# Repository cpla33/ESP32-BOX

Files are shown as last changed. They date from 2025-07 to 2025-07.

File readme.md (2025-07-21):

# ESP32-BOX

The device has been designed around regular ESP32-module to be fitted inside DIN-rail mounting enclosure. The board designed to be compact as much as possible. It takes 3 DIN-rail positions only.

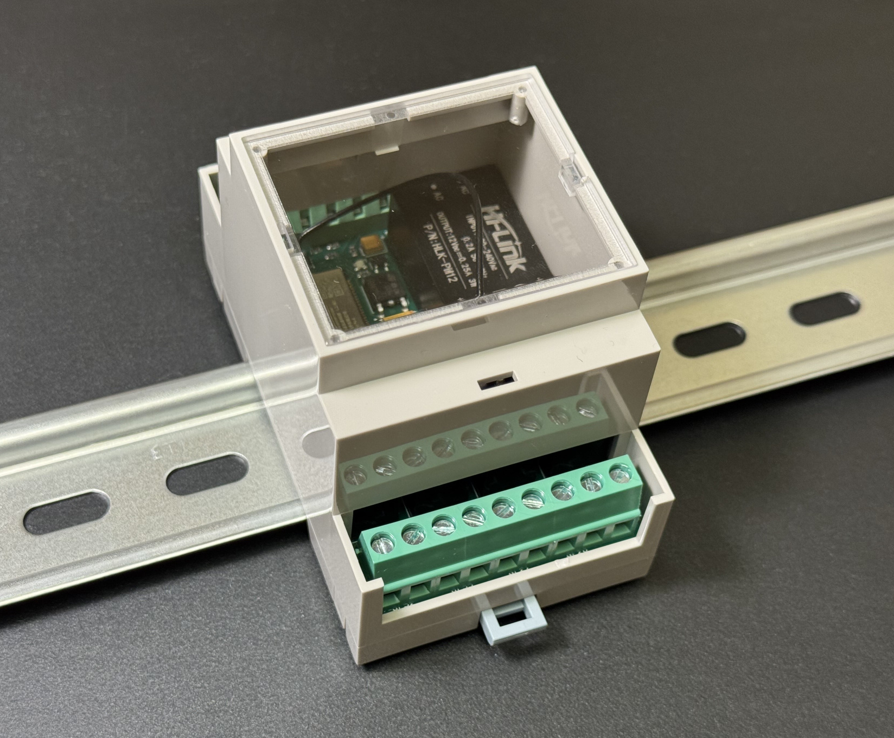
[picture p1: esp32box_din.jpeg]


------

### Main features:

- The **ESP32-BOX** has internal AC/DC-converter. Thus it could be powered from the regular AC line (i.e. wall socket) 100-240V (no external AC/DC adapters needed);
- The **ESP32-BOX** provides 4 optically isolated Relay outputs (up to 10A/250V or 5A/30V each). Each relay output has its own LED-indicator.
- The **ESP32-BOX** provides 4 GPIOs. Two of them could be used as I2C-line.
- All the inputs and outputs of the **ESP32-BOX** are implemented as reliable screw terminals.
- The **ESP32-BOX** has onboard RGB-led, which could be used for multiple status indications on your taste.
- The top part of the enclosure is transparent. So the LEDs could be easily observed from the outside.
- The **ESP32-BOX** provides powerful external antenna, which is located inside the enclosure. Thanks to `uFL/IPEX1` header any other suitable antenna could be used instead.
- The **ESP32-BOX** is equipped with the external +3dBi antenna hidden inside the enclosure;
- The **ESP32-BOX** could be programmed with the USB Type-C cable (no buttons required).
- The **ESP32-BOX** could be programmed with the ; write your sketches whenever you want: Arduino, CircuitPython, MicroPython or ESP-IDF.
- Finally, **ESP32-BOX** is **ESPHome**-compatible!

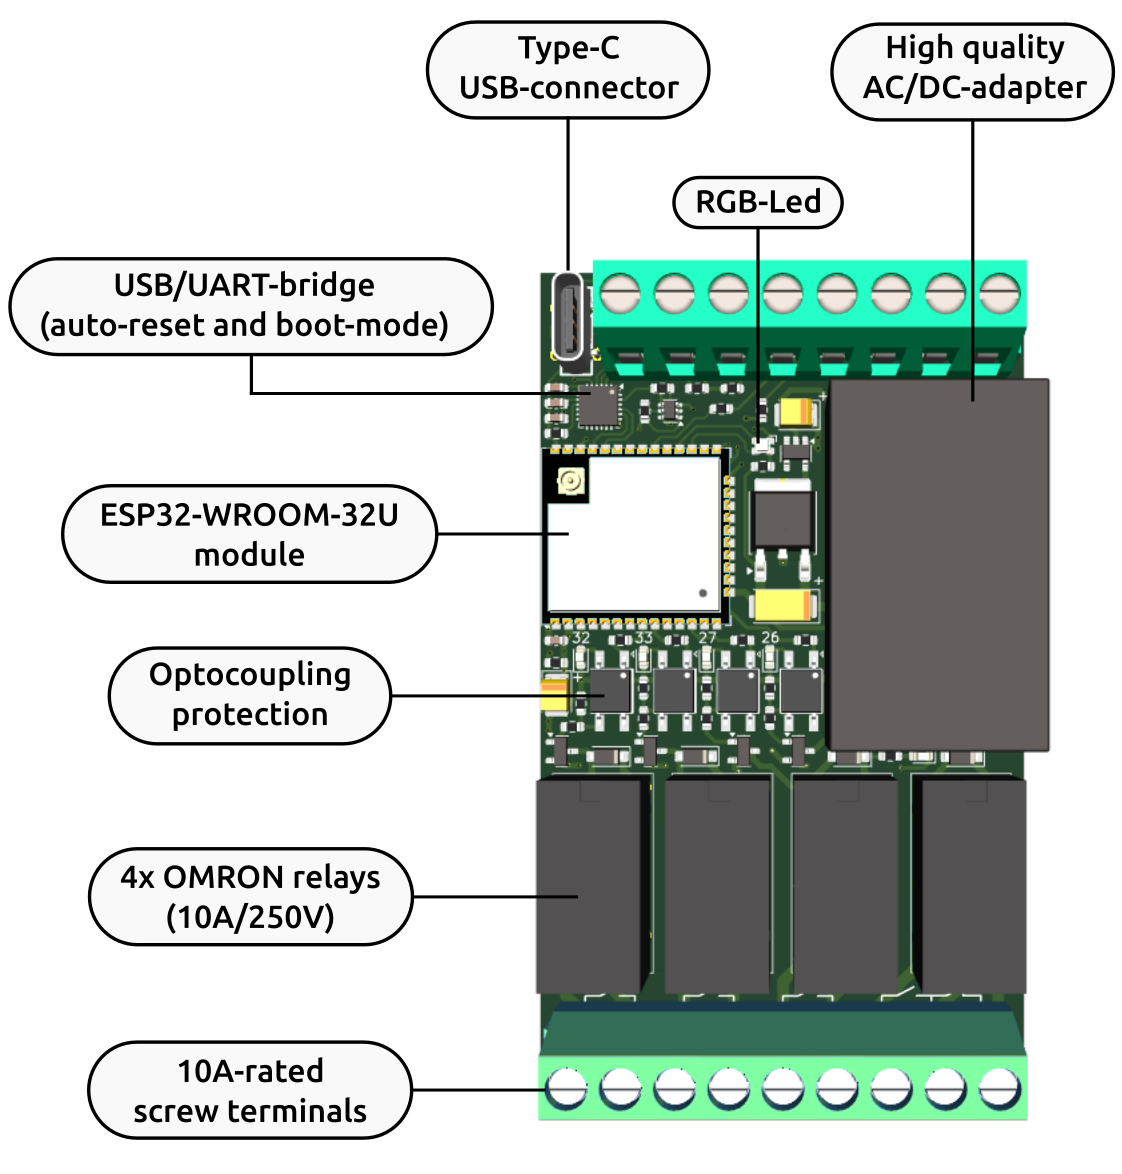
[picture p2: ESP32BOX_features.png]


------

### Programming:

A number of different IDEs and programming languages of any taste as below are allowed to program the **ESP32-BOX**:

[ESPHome](https://www.binarytechlabs.com/how-to-flash-esphome-firmware-a-friendly-step-by-step-guide/)

[Arduino](https://randomnerdtutorials.com/installing-the-esp32-board-in-arduino-ide-windows-instructions/)

[CircuitPython](FIRMWARE/CIRCUITPYTHON/readme_circuitpython.md)

[MicroPython](https://micropython.org/download/ESP32_GENERIC/)

[ESP-IDF](https://docs.espressif.com/projects/esp-idf/en/stable/esp32/get-started/index.html)

A couple of different examples could be found in the [FIRMWARE](FIRMWARE/) folder.

------

### Pinout:

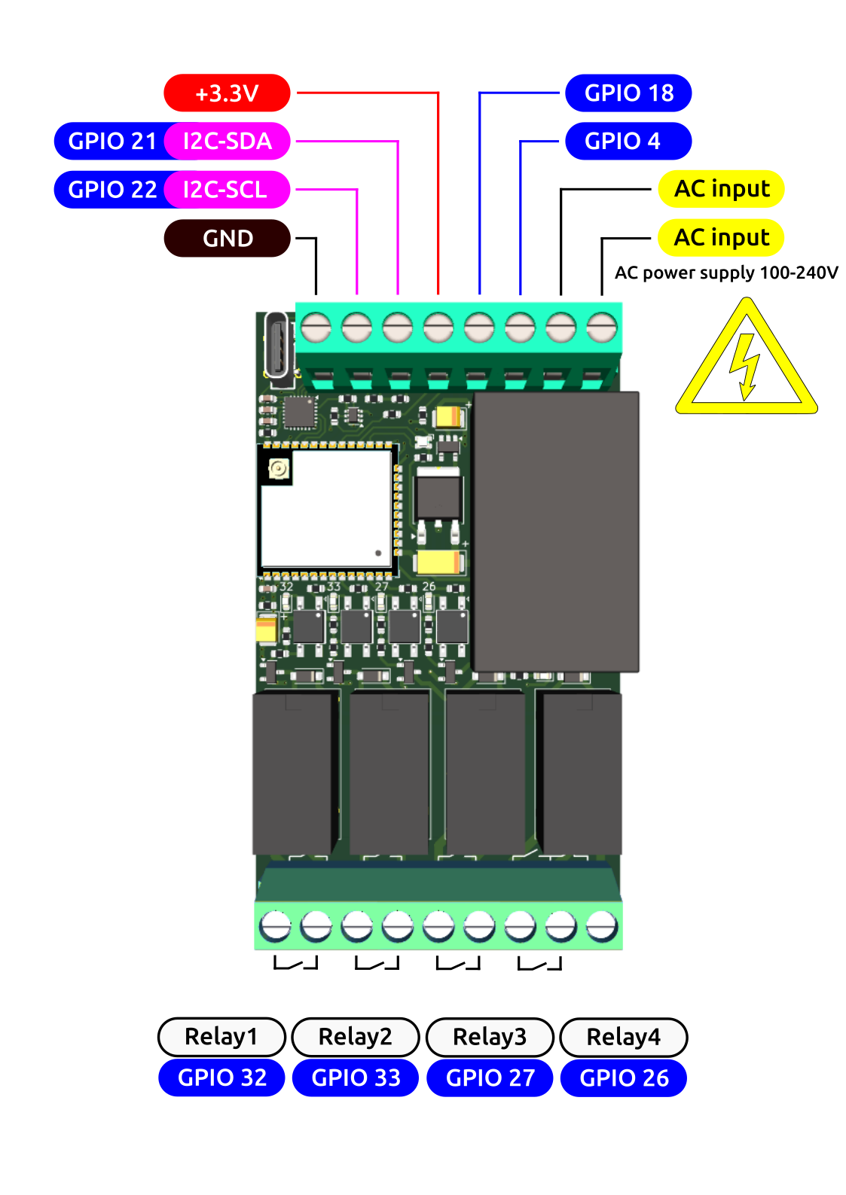
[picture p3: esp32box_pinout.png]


------

### Schematics:

Refer to the [schematics](HARDWARE/esp32_box_single.pdf) if needed.

------

Coming soon at Lectronz.com

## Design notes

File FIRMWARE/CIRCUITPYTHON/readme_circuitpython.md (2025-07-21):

### Uploading the CircuitPython firmware in Linux:

1. Download [latest firmware](https://circuitpython.org/board/espressif_esp32_devkitc_v4_wroom_32e/) file from official CircuitPython web-site.

2. Install [esptool](https://github.com/espressif/esptool) as below:

```bash
python3 -m pip install --upgrade esptool
```

3. Plug-in USB-C cable and check for device connection:

```bash
ls /dev/ttyACM0
```

4. Erase flash as below:

```bash
esptool.py --chip esp32 --port /dev/ttyACM0 erase_flash
```

5. Write the CircuitPython firmware:

```bash
esptool.py --chip esp32 --port /dev/ttyACM0 \
           --baud 460800 \
           --after hard_reset \
           write_flash -z 0x0 adafruit-circuitpython-espressif_esp32_devkitc_v4_wroom_32e-en_US-9.2.8.bin
           
```

More options could be found [here](https://learn.adafruit.com/circuitpython-with-esp32-quick-start/command-line-esptool).

------

### Code examples:

Code examples could be found in [EXAMPLES](EXAMPLES/test_io.py) directory.

------
[Back](../../readme.md)

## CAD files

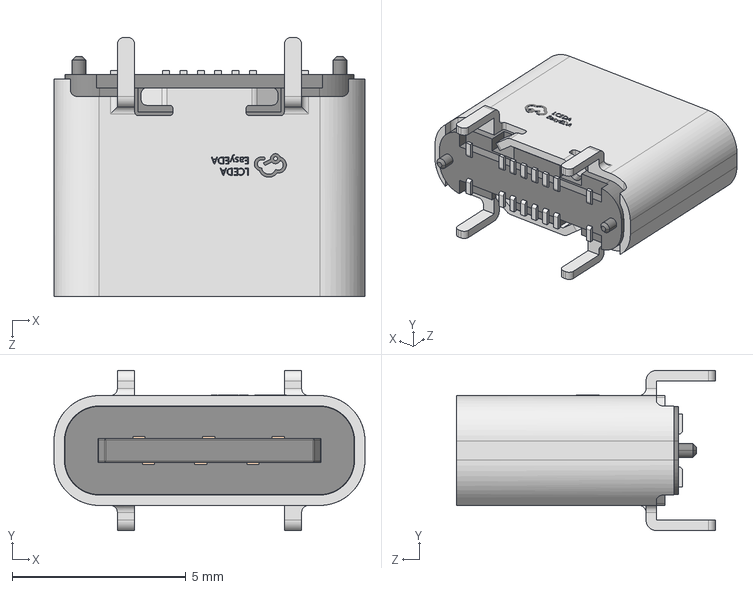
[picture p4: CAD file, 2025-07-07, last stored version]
HARDWARE/kicad/esp32_box_single/models/C3151749_TYPE-C-SMD_USB4120-03-C.step
8.94 x 4.60 x 7.45 mm

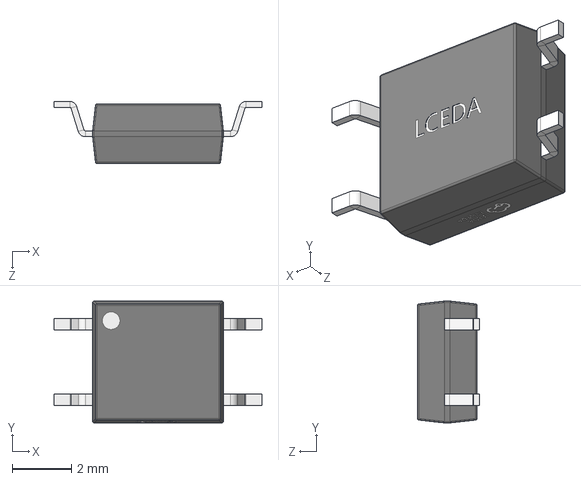
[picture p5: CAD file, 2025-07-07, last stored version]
HARDWARE/kicad/esp32_box_single/models/C42381015_EL357_OPTO-SMD-4_L4.4-W4.1-P2.54-LS7.0-TL.step
7.00 x 4.10 x 2.08 mm

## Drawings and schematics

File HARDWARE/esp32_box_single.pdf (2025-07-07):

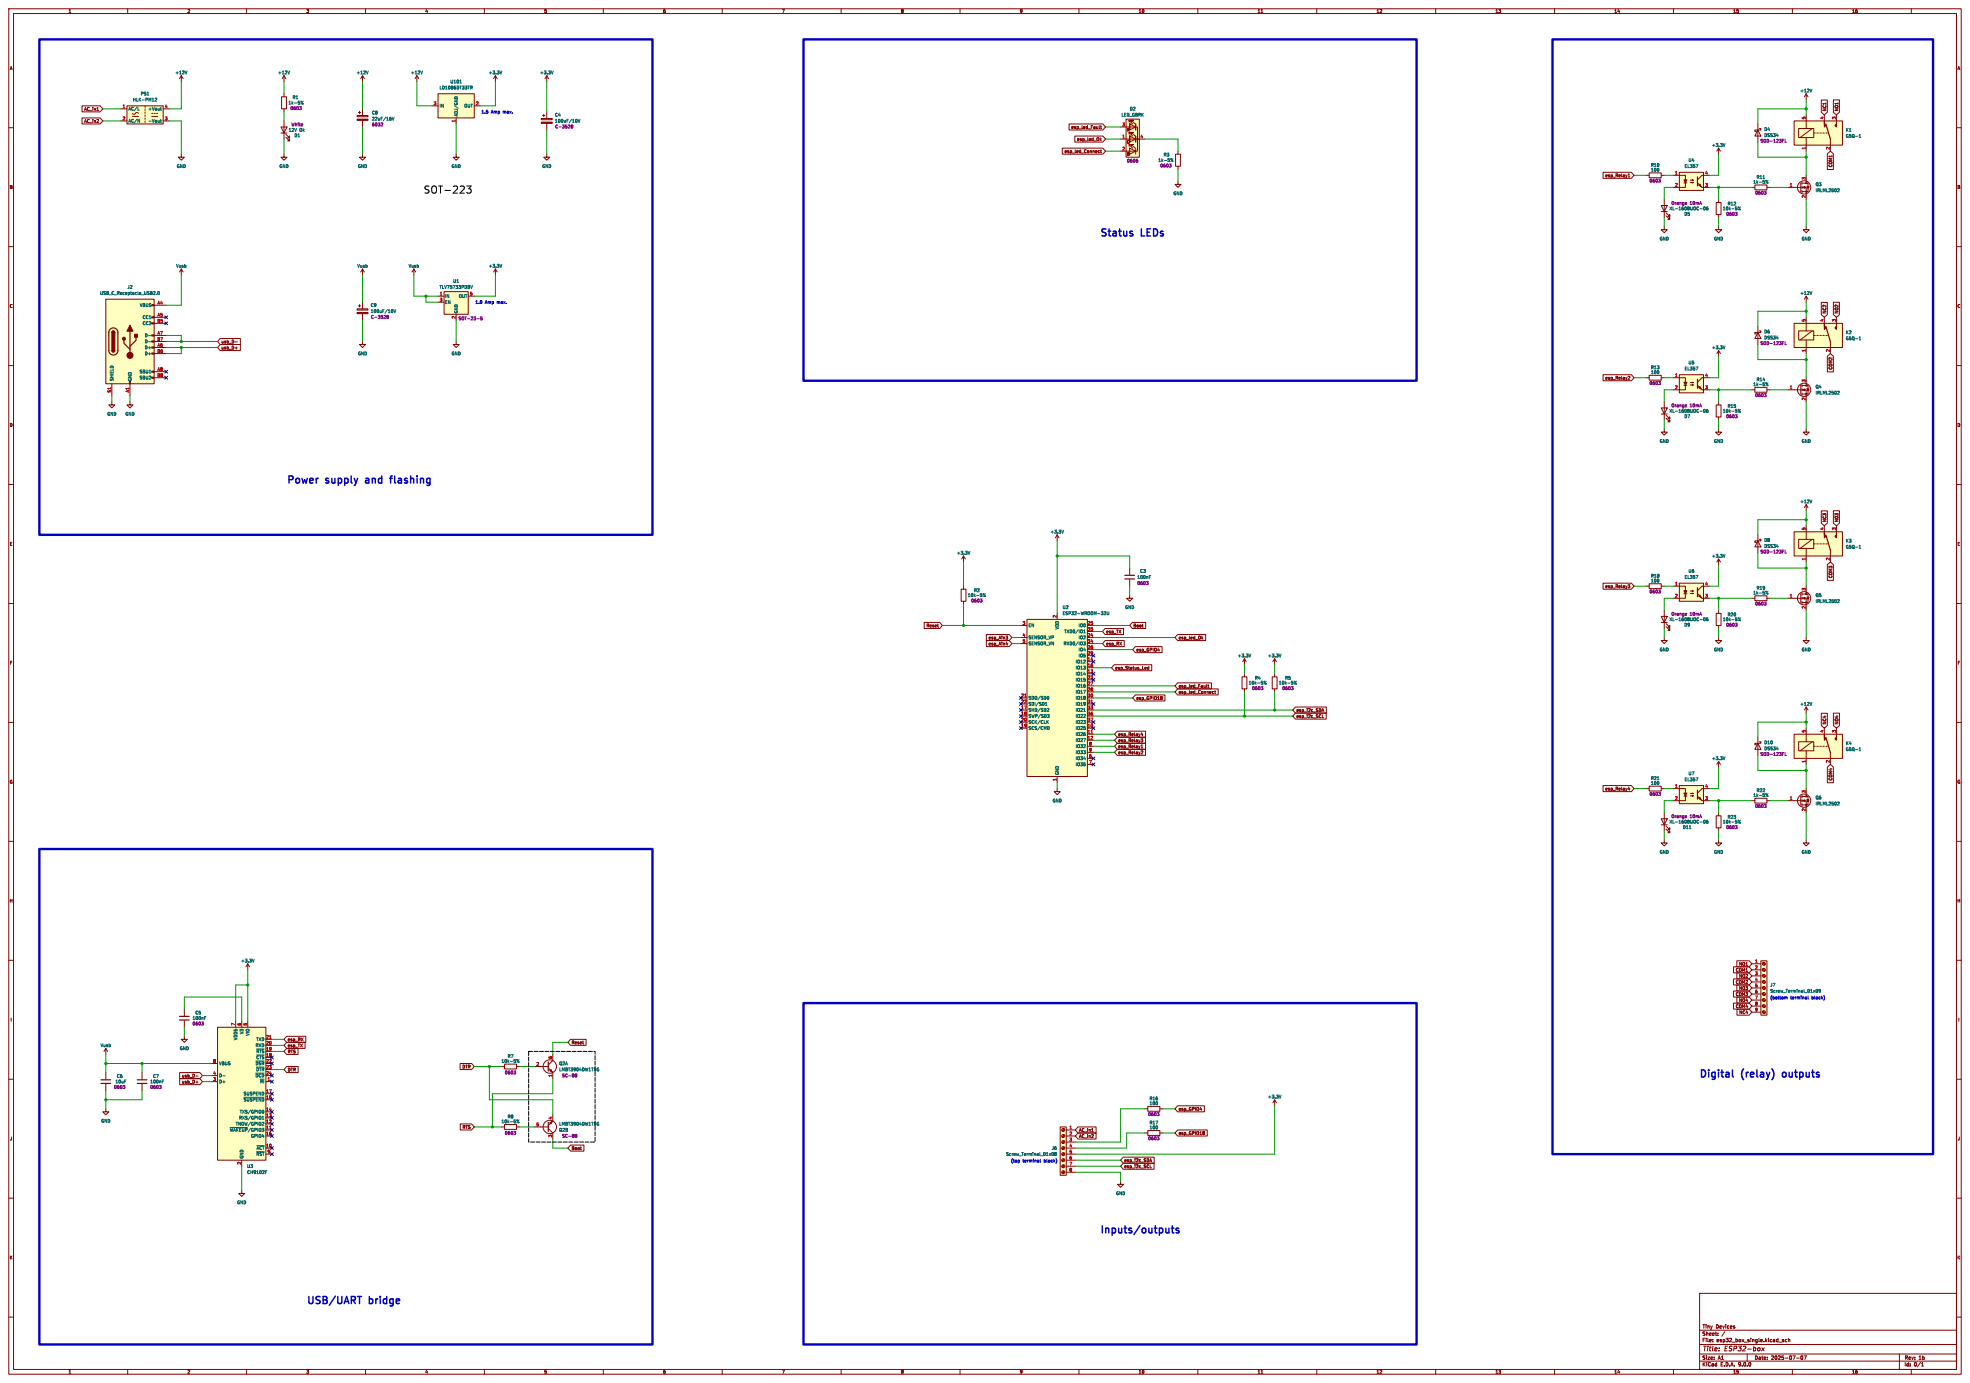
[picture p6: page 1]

Power supply and flashing

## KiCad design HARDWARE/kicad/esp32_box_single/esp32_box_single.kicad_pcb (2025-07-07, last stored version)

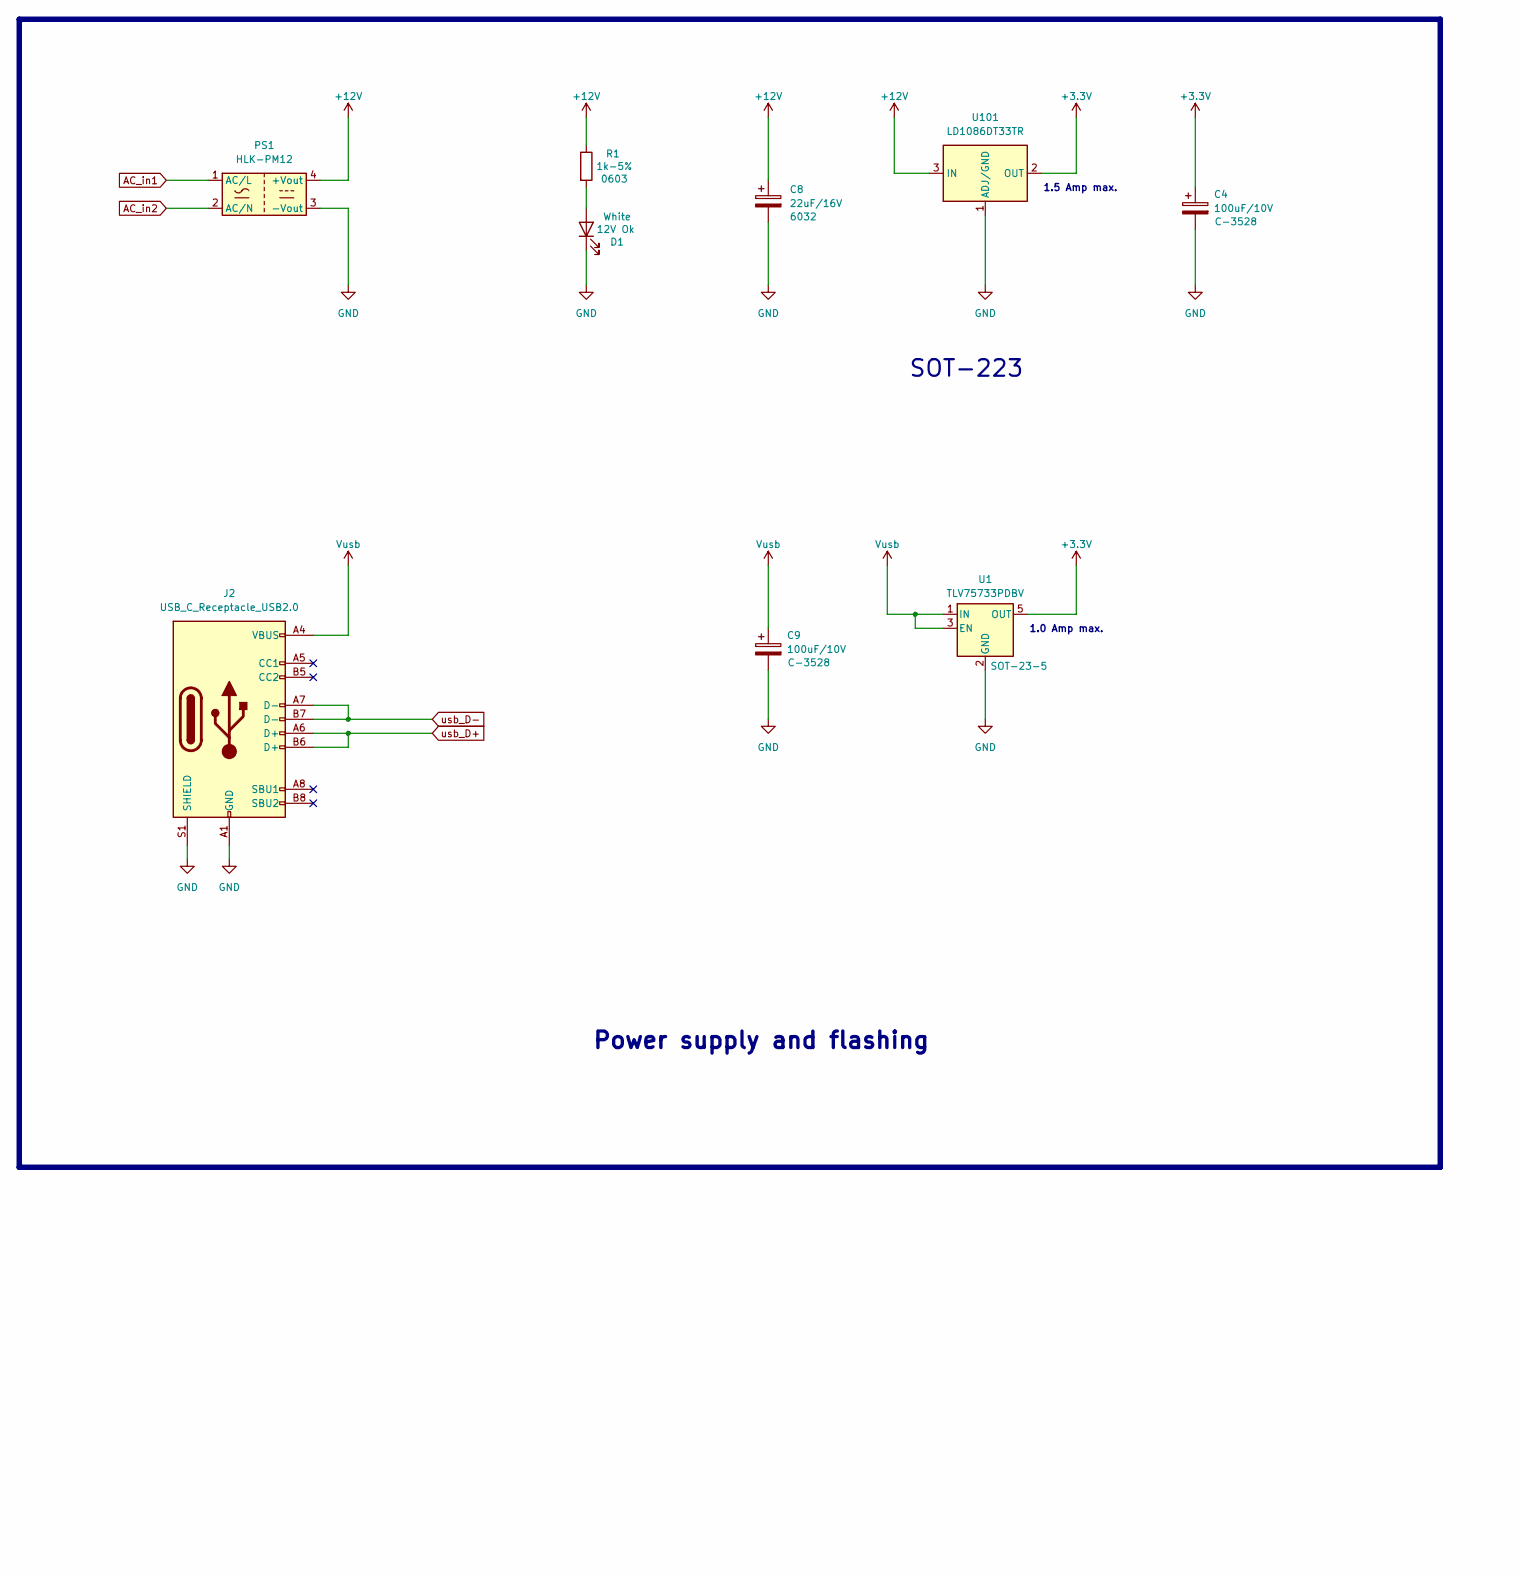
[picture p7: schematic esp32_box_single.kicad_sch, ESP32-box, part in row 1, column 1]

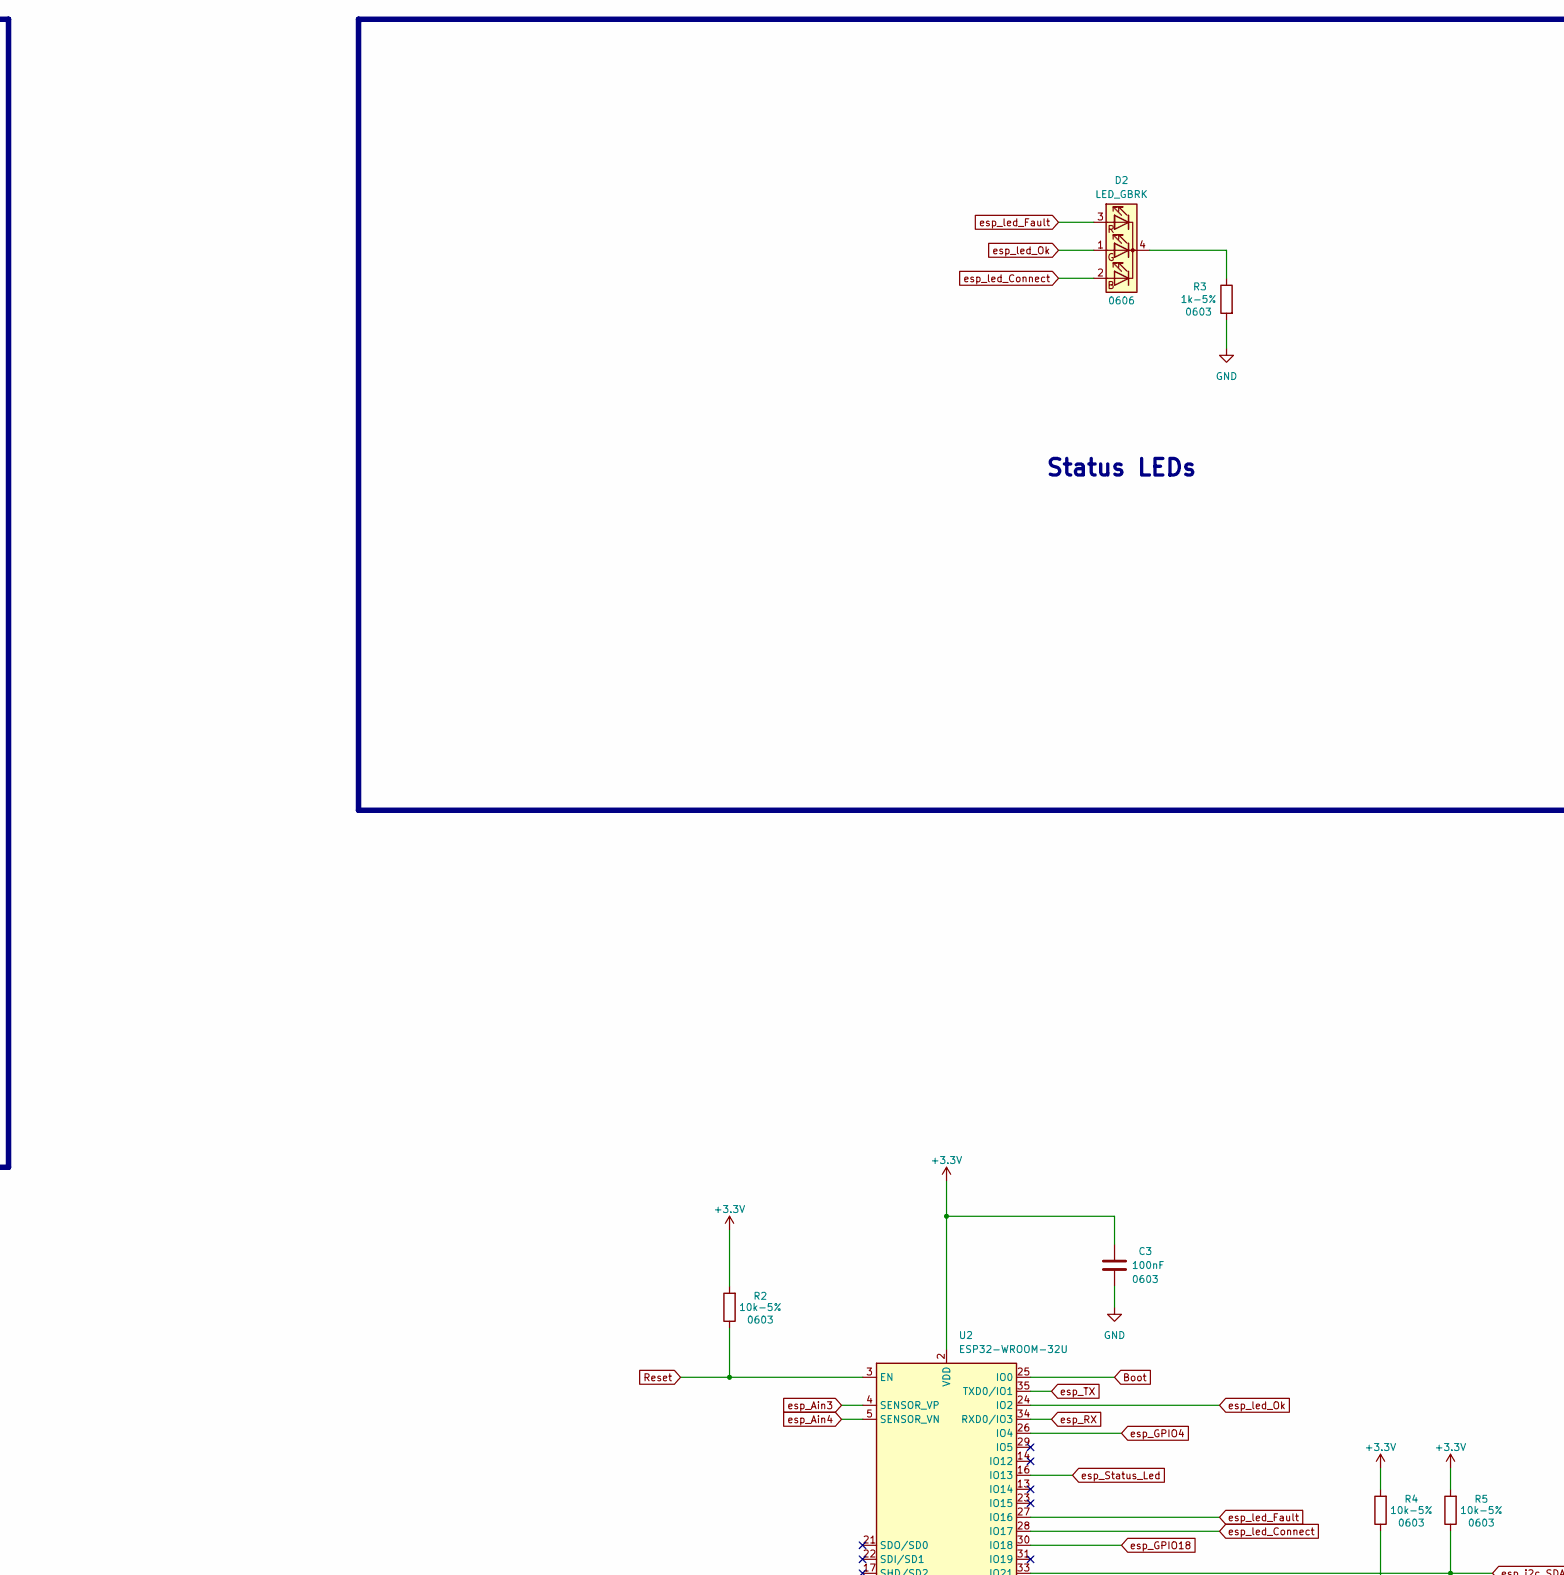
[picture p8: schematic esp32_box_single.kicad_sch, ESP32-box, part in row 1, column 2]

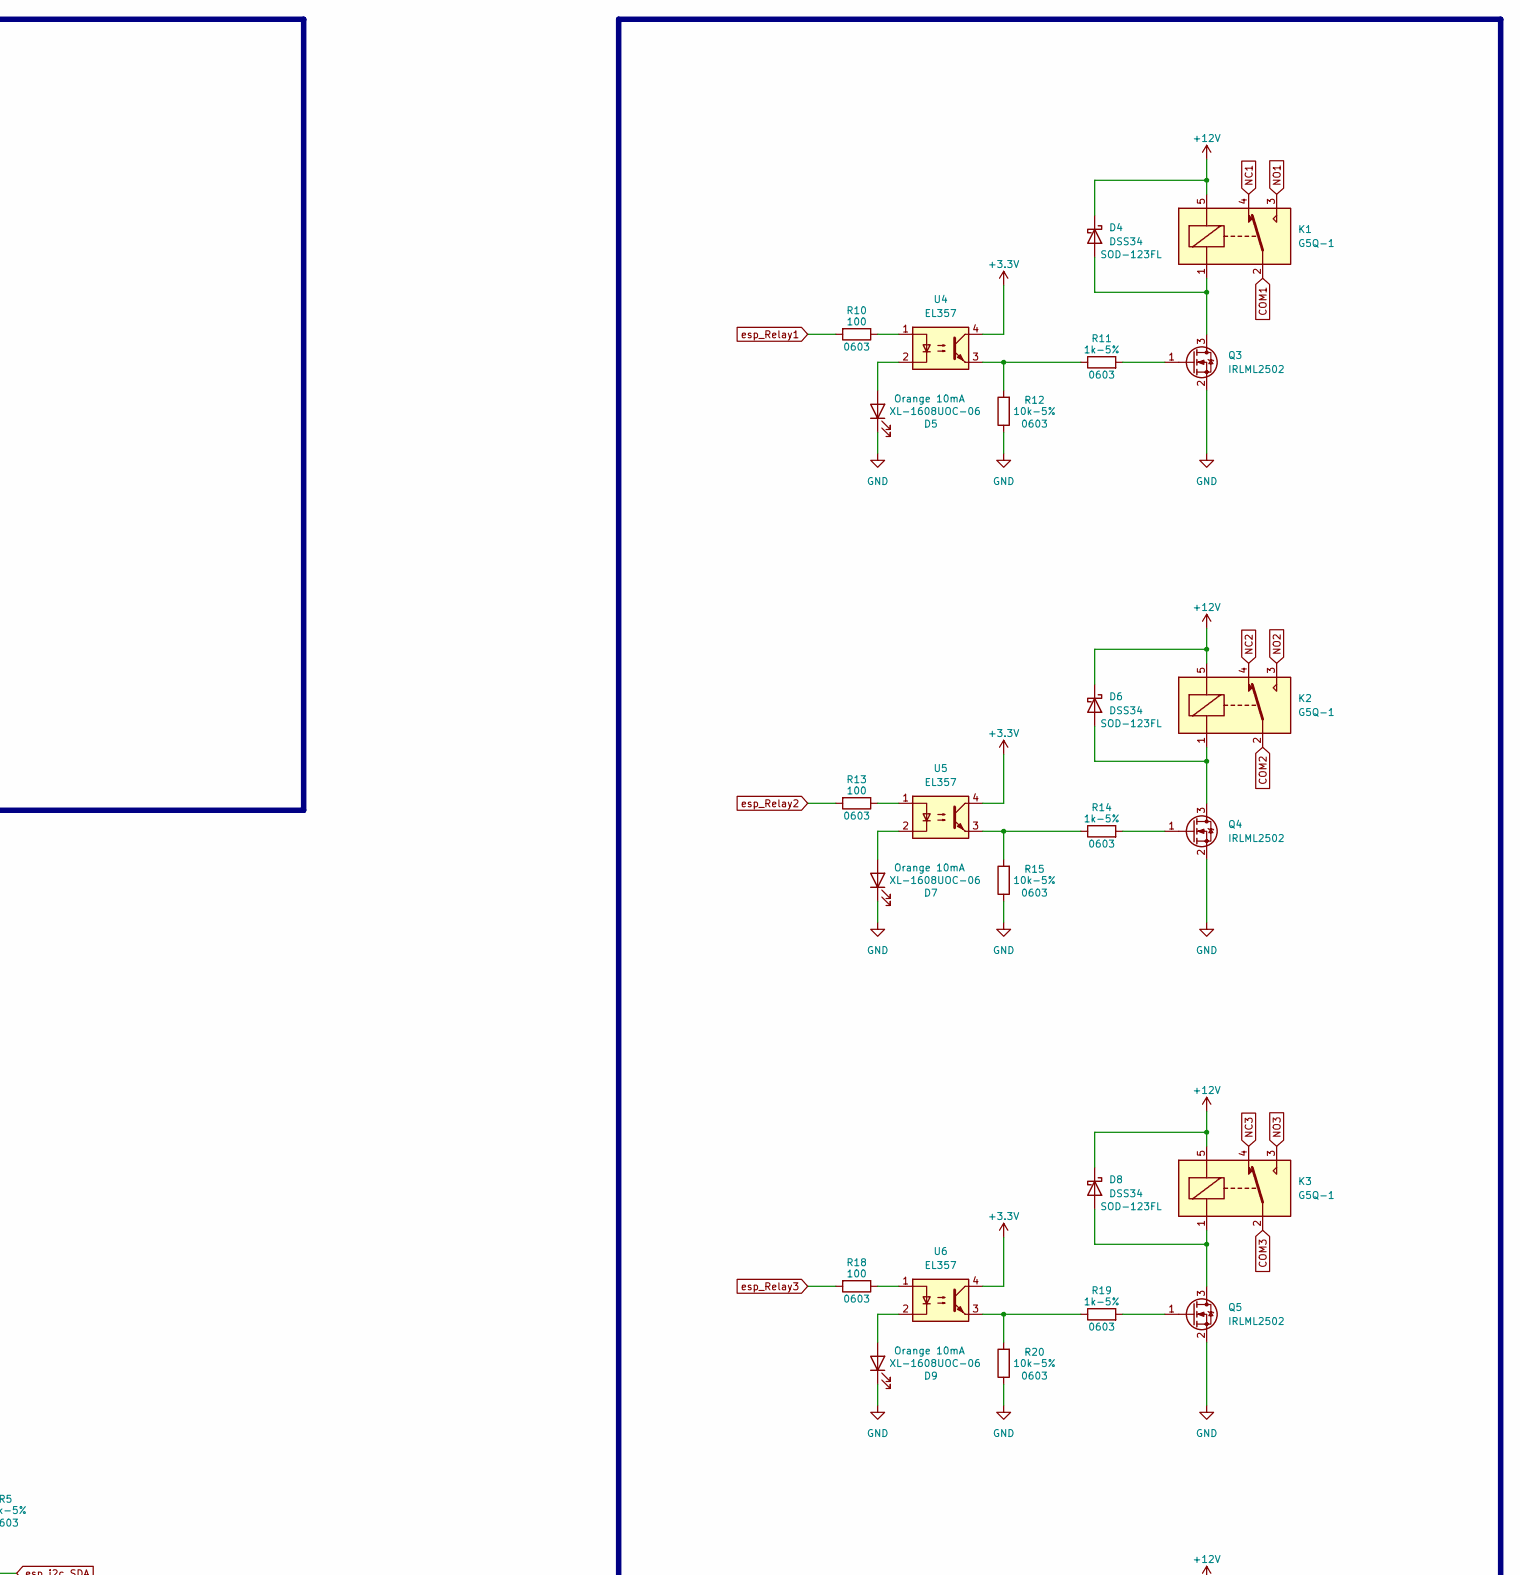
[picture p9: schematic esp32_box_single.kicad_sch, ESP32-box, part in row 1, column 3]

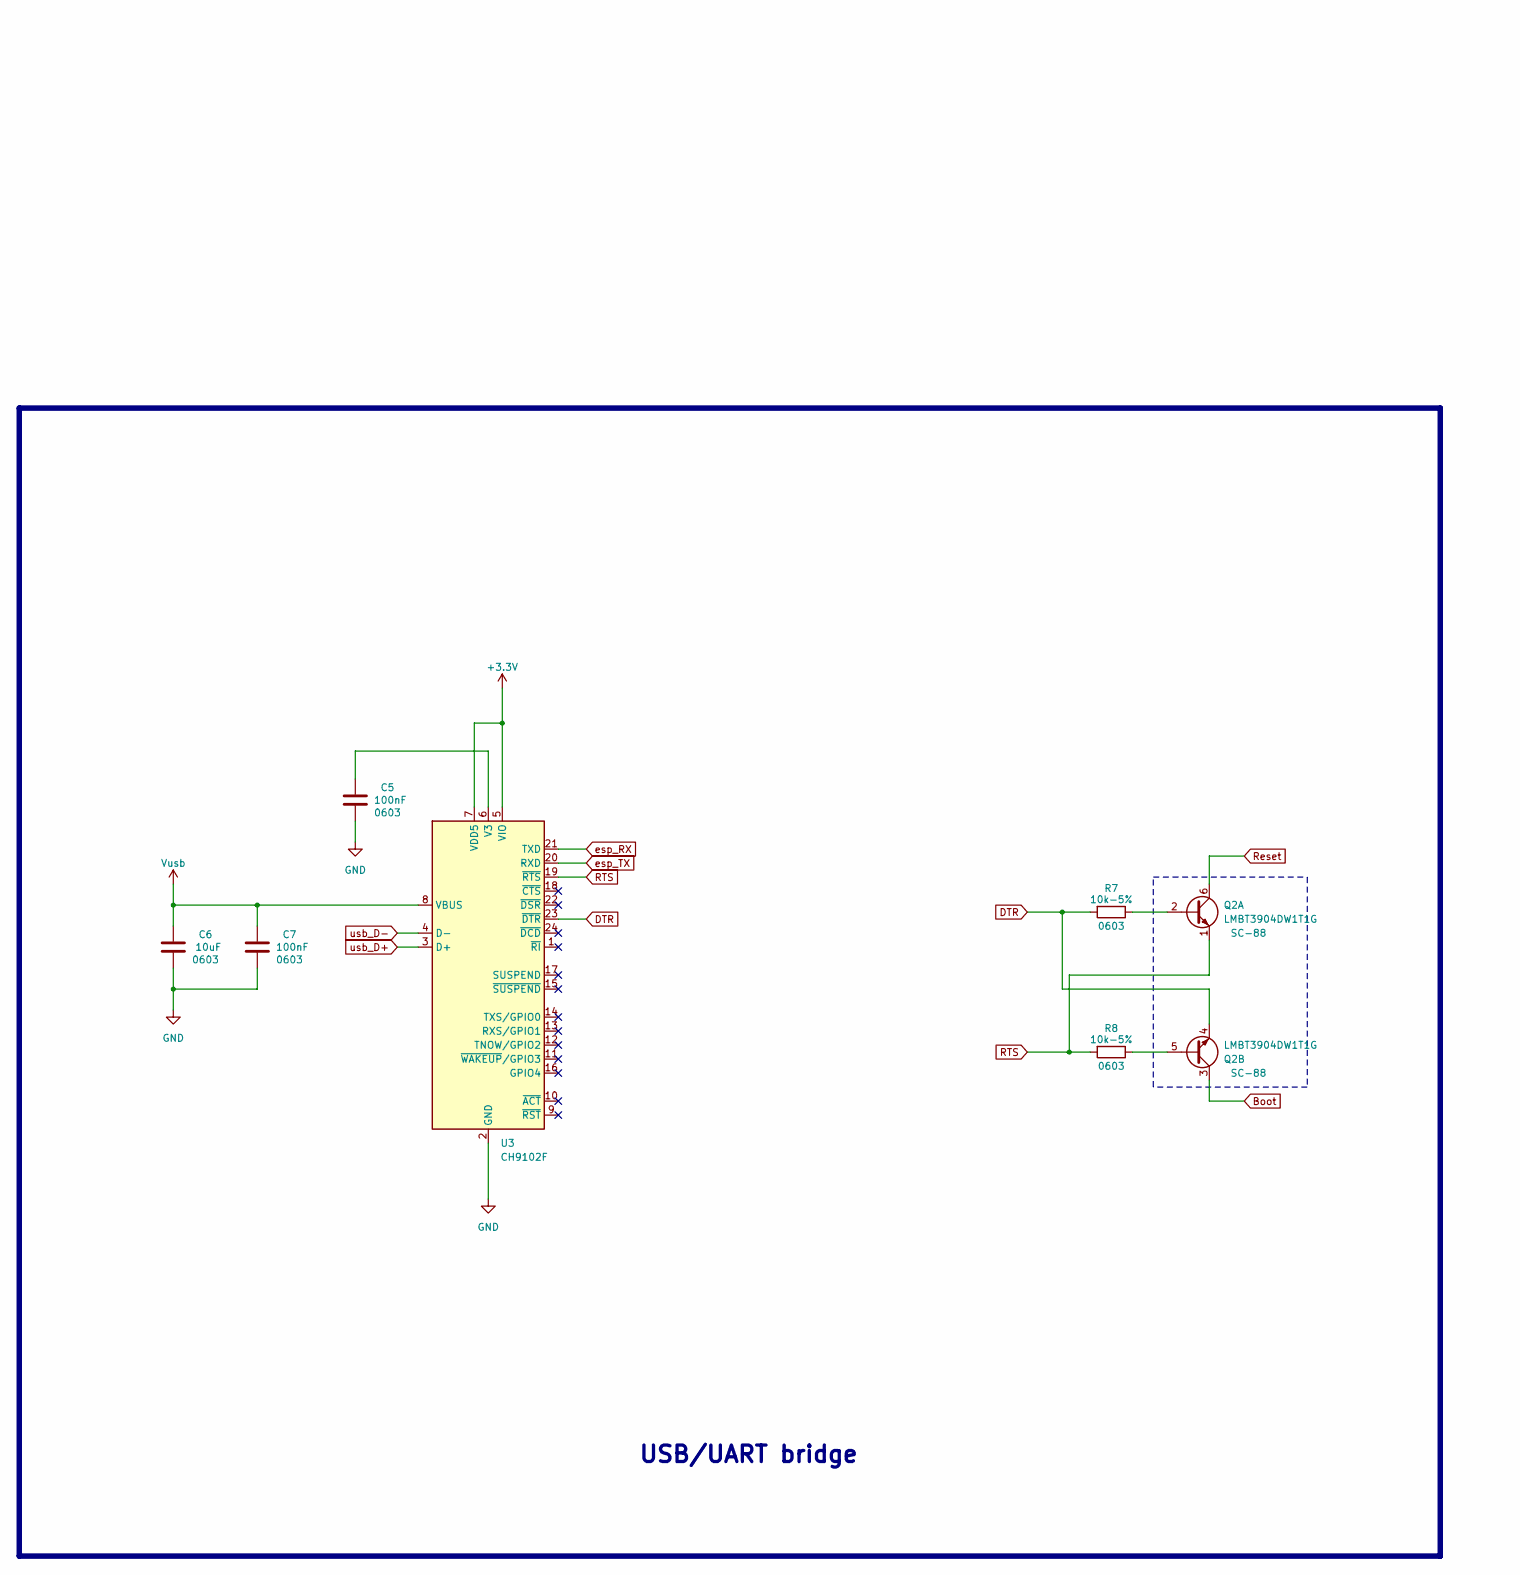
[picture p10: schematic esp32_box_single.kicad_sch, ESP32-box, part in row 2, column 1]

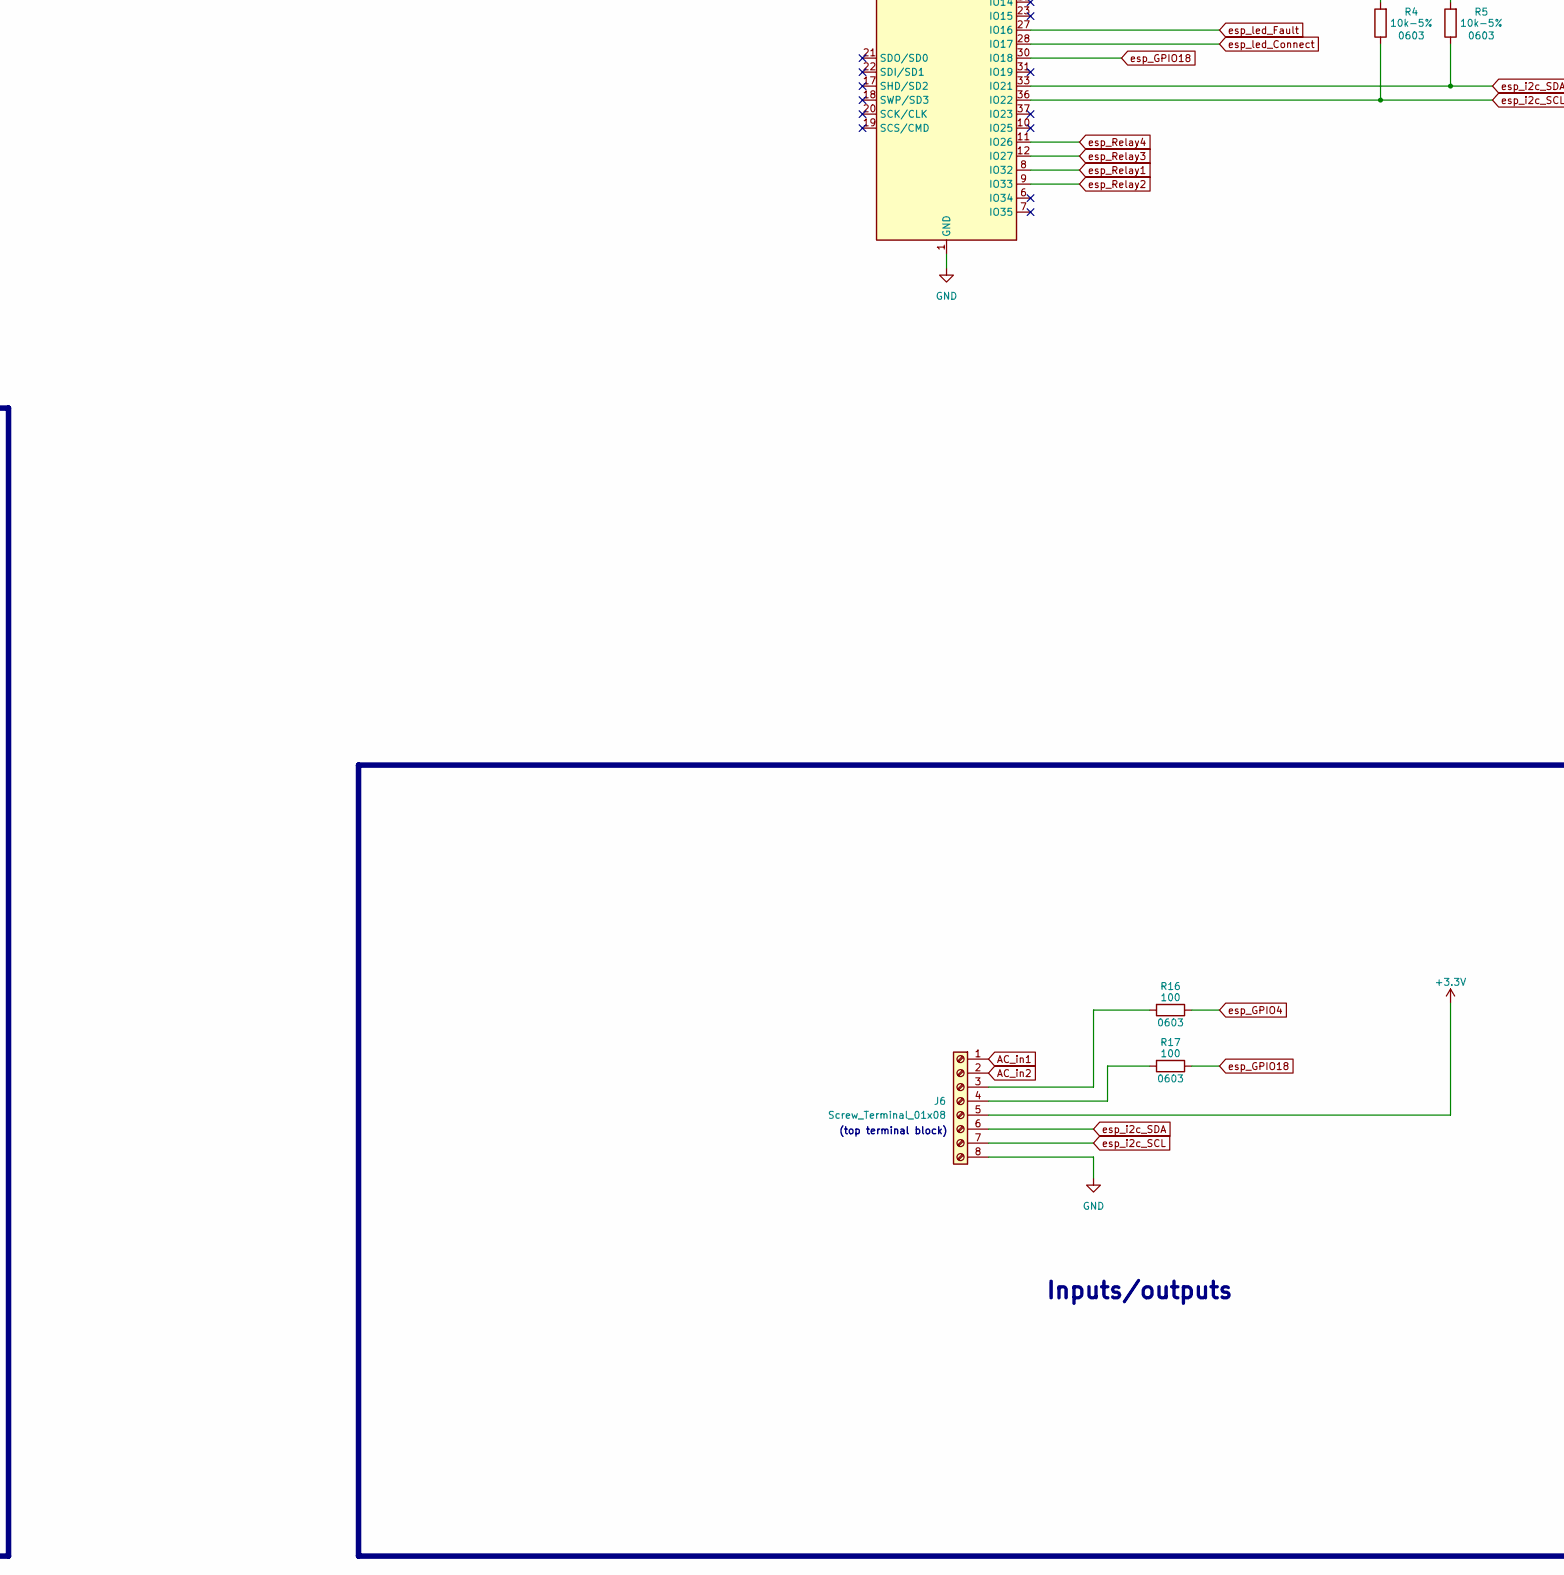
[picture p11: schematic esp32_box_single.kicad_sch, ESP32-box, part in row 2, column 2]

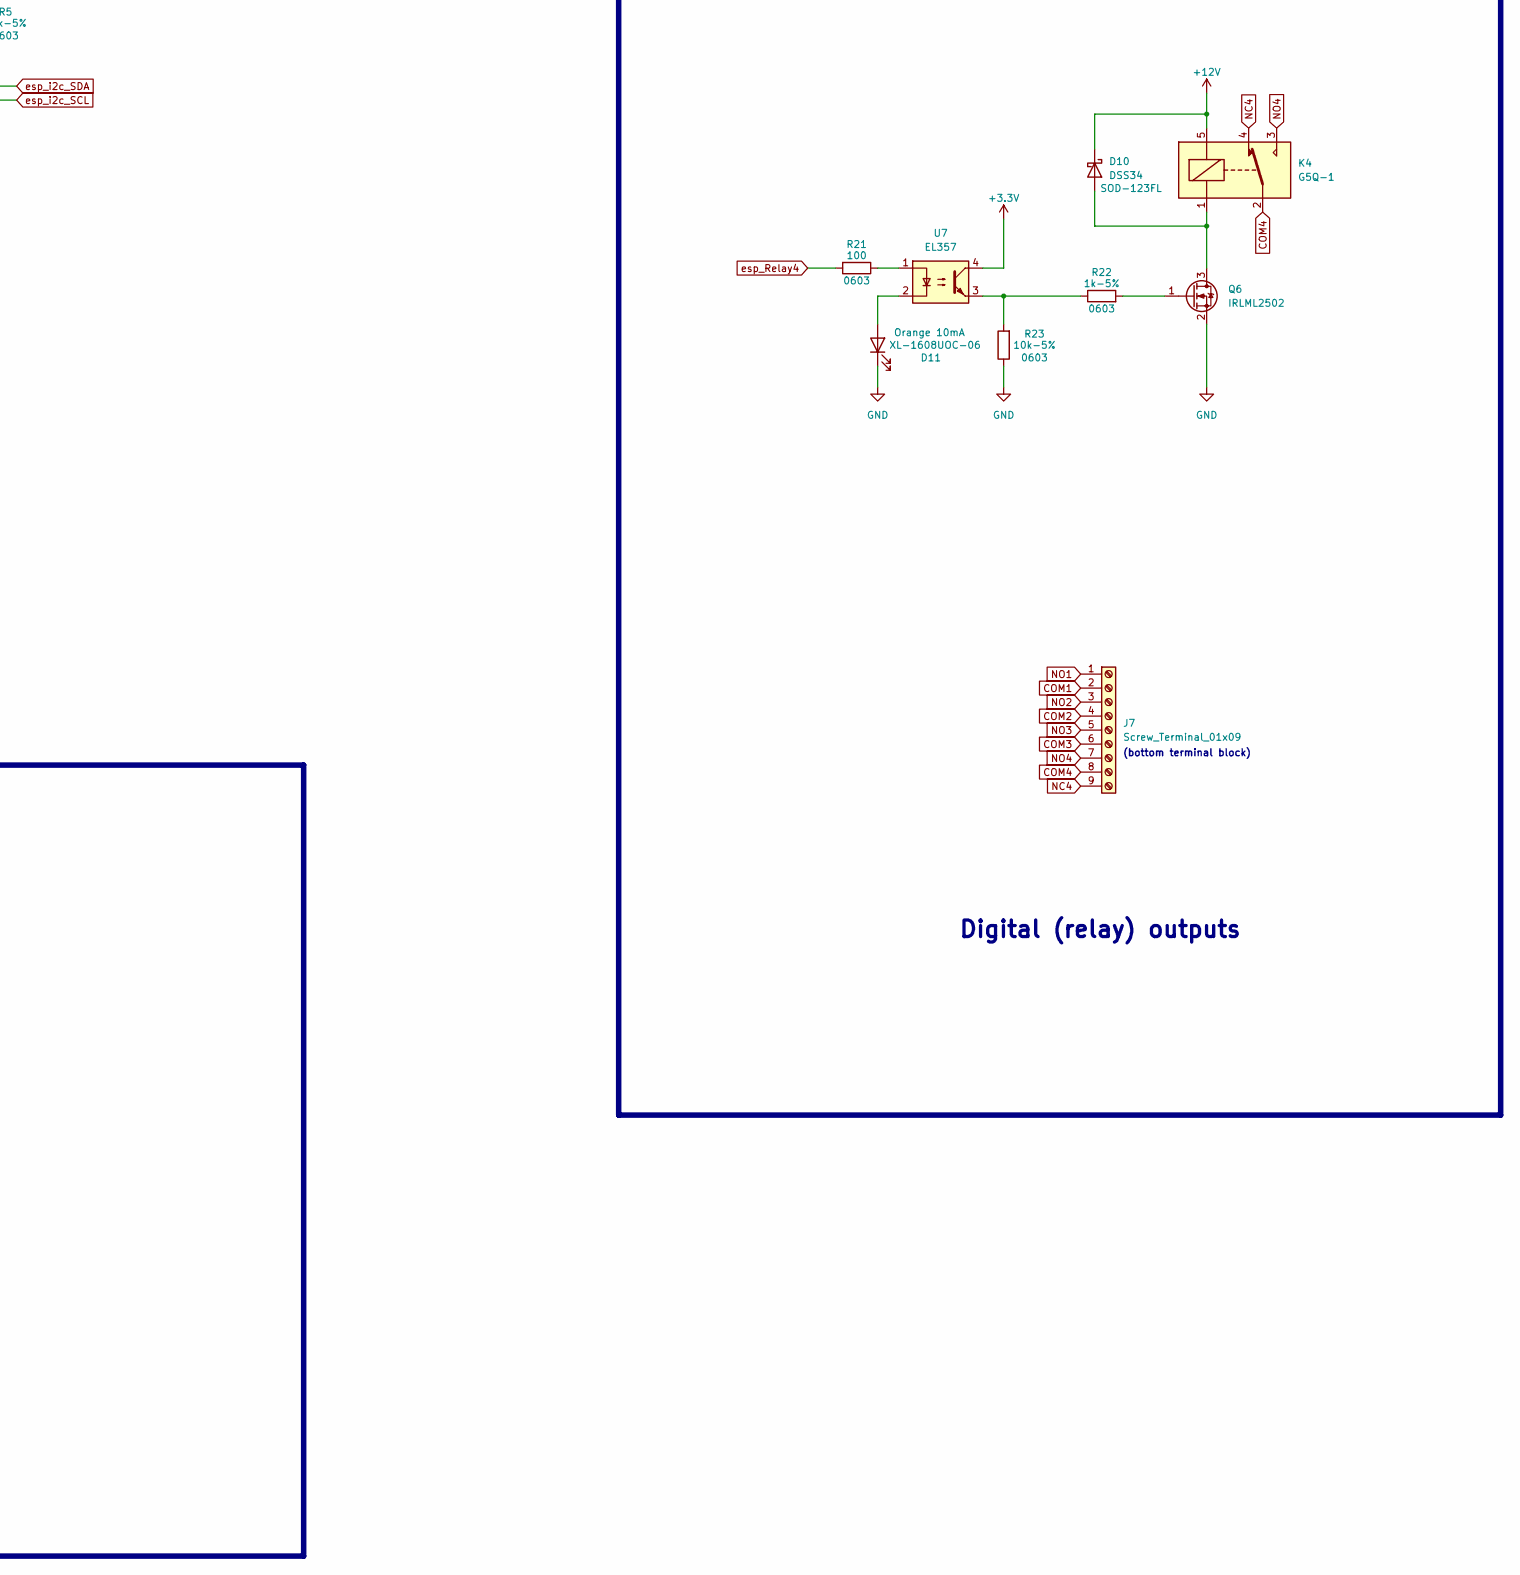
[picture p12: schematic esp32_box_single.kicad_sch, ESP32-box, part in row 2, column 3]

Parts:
C3, C5, C7: 100nF; C_0603_1608Metric; LCSC part C1591
C4, C9: 100uF/10V; CP_EIA-3528-21_Kemet-B; LCSC part C122271
C6: 10uF; C_0603_1608Metric; LCSC part C19702
C8: 22uF/16V; CP_EIA-6032-20_AVX-F; LCSC part C11376
D1: 12V Ok; LED_0603_1608Metric; LCSC part C965808
D2: LED_GBRK; C273611_RGB_Led_0606; LCSC part C273611
D4, D6, D8, D10: DSS34; C2923958_DSS34_SOD-123FL; LCSC part C2923958
D5, D7, D9, D11: XL-1608UOC-06; LED_0603_1608Metric; LCSC part C434425
J2: USB_C_Receptacle_USB2.0; C3151749_USB_TYPE-C_Vertical; LCSC part C3151749
J6: Screw_Terminal_01x08; TerminalBlock_RND_205-00238_1x08_P5.08mm_Horizontal
J7: Screw_Terminal_01x09; TerminalBlock_RND_205-00239_1x09_P5.08mm_Horizontal
K1, K2, K3, K4: G5Q-1; C225715_Omron-G5Q
PS1: HLK-PM12; C209905_HLK-PM12_mod; LCSC part C209905
Q2: LMBT3904DW1T1G; SOT-363_SC-70-6; LCSC part C131781
Q3, Q4, Q5, Q6: IRLML2502; SOT-23; LCSC part C347503
R1, R3, R11, R14, R19, R22: 1k-5%; R_0603_1608Metric; LCSC part C2907113
R2, R4, R5, R7, R8, R12, R15, R20, R23: 10k-5%; R_0603_1608Metric; LCSC part C25804
R10, R13, R16, R17, R18, R21: 100; R_0603_1608Metric; LCSC part C2907089
U1: TLV75733PDBV; SOT-23-5; LCSC part C485517
U2: ESP32-WROOM-32U; LCSC part C328062
U3: CH9102F; QFN-24-1EP_4x4mm_P0.5mm_EP2.6x2.6mm; LCSC part C2858418
U4, U5, U6, U7: EL357; C42381015_EL357_L4.4-W4.1-P2.54-LS7.0-TL; LCSC part C42381015
U101: LD1086DT33TR; TO-252-2; LCSC part C12051

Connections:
+3.3V: C3.2, C4.1, J6.5, R2.2, R4.2, R5.2, U1.5 (OUT), U2.2 (VDD), U3.5 (VIO), U3.7 (VDD5), U4.4, U5.4, U6.4, U7.4, U101.2 (OUT)
+12V: C8.1, D4.1 (K), D6.1 (K), D8.1 (K), D10.1 (K), K1.5, K2.5, K3.5, K4.5, PS1.4 (+Vout), R1.1, U101.3 (IN)
AC_in1: J6.1, PS1.1 (AC/L)
AC_in2: J6.2, PS1.2 (AC/N)
Boot: Q2.3 (C2), U2.25 (IO0)
COM1: J7.2, K1.2
COM2: J7.4, K2.2
COM3: J7.6, K3.2
COM4: J7.8, K4.2
DTR: Q2.4 (E2), R7.2, U3.23 (~DTR)
GND: C3.1, C4.2, C5.1, C6.1, C7.1, C8.2, C9.2, D1.1 (K), D5.1 (K), D7.1 (K), D9.1 (K), D11.1 (K), J2.A1 (GND), J2.A12 (GND), J2.B1 (GND), J2.B12 (GND), J2.S1 (SHIELD), J6.8, PS1.3 (-Vout), Q3.2 (S), Q4.2 (S), Q5.2 (S), Q6.2 (S), R3.2, R12.1, R15.1, R20.1, R23.1, U1.2 (GND), U2.1 (GND), U2.15 (GND), U2.38 (GND), U2.39 (GND), U3.2 (GND), U3.25 (GND), U101.1 (ADJ/GND); also elsewhere on the board
NC1: K1.4
NC2: K2.4
NC3: K3.4
NC4: J7.9, K4.4
NO1: J7.1, K1.3
NO2: J7.3, K2.3
NO3: J7.5, K3.3
NO4: J7.7, K4.3
unnamed: D1.2 (A), R1.2
unnamed: D2.4 (K), R3.1
unnamed: D4.2 (A), K1.1, Q3.3 (D)
unnamed: D5.2 (A), U4.2
unnamed: D6.2 (A), K2.1, Q4.3 (D)
unnamed: D7.2 (A), U5.2
unnamed: D8.2 (A), K3.1, Q5.3 (D)
unnamed: D9.2 (A), U6.2
unnamed: D10.2 (A), K4.1, Q6.3 (D)
unnamed: D11.2 (A), U7.2
unnamed: J6.3, R16.2
unnamed: J6.4, R17.2
unnamed: Q2.2 (B1), R7.1
unnamed: Q2.5 (B2), R8.1
unnamed: Q3.1 (G), R11.2
unnamed: Q4.1 (G), R14.2
unnamed: Q5.1 (G), R19.2
unnamed: Q6.1 (G), R22.2
unnamed: R10.1, U4.1
unnamed: R11.1, R12.2, U4.3
unnamed: R13.1, U5.1
unnamed: R14.1, R15.2, U5.3
unnamed: R18.1, U6.1
unnamed: R19.1, R20.2, U6.3
unnamed: R21.1, U7.1
unnamed: R22.1, R23.2, U7.3
unnamed: C5.2, U3.6 (V3)
unnamed 46: U3.9 (~RST); also elsewhere on the board
RTS: Q2.1 (E1), R8.2, U3.19 (~RTS)
Reset: Q2.6 (C1), R2.1, U2.3 (EN)
Vusb: C6.2, C7.2, C9.1, J2.A4 (VBUS), J2.A9 (VBUS), J2.B4 (VBUS), J2.B9 (VBUS), U1.1 (IN), U1.3 (EN), U3.8 (VBUS)
esp_Ain1: U2.6 (IO34)
esp_Ain2: U2.7 (IO35)
esp_Ain3: U2.4 (SENSOR_VP)
esp_Ain4: U2.5 (SENSOR_VN)
esp_GPIO4: R16.1, U2.26 (IO4)
esp_GPIO18: R17.1, U2.30 (IO18)
esp_GPIO19: U2.31 (IO19)
esp_GPIO23: U2.37 (IO23)
esp_RX: U2.34 (RXD0/IO3), U3.21 (TXD)
esp_Relay1: R10.2, U2.8 (IO32)
esp_Relay2: R13.2, U2.9 (IO33)
esp_Relay3: R18.2, U2.12 (IO27)
esp_Relay4: R21.2, U2.11 (IO26)
esp_Status_Led: U2.16 (IO13)
esp_TX: U2.35 (TXD0/IO1), U3.20 (RXD)
esp_i2c_SCL: J6.7, R4.1, U2.36 (IO22)
esp_i2c_SDA: J6.6, R5.1, U2.33 (IO21)
esp_led_Connect: D2.2 (BA), U2.28 (IO17)
esp_led_Fault: D2.3 (RA), U2.27 (IO16)
esp_led_Ok: D2.1 (GA), U2.24 (IO2)
usb_D+: J2.A6 (D+), J2.B6 (D+), U3.3 (D+)
usb_D-: J2.A7 (D-), J2.B7 (D-), U3.4 (D-)

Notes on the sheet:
Digital (relay) outputs
USB/UART bridge
Power supply and flashing
(bottom terminal block)
Status LEDs
Inputs/outputs
SOT-223
1.5 Amp max.
(top terminal block)
1.0 Amp max.

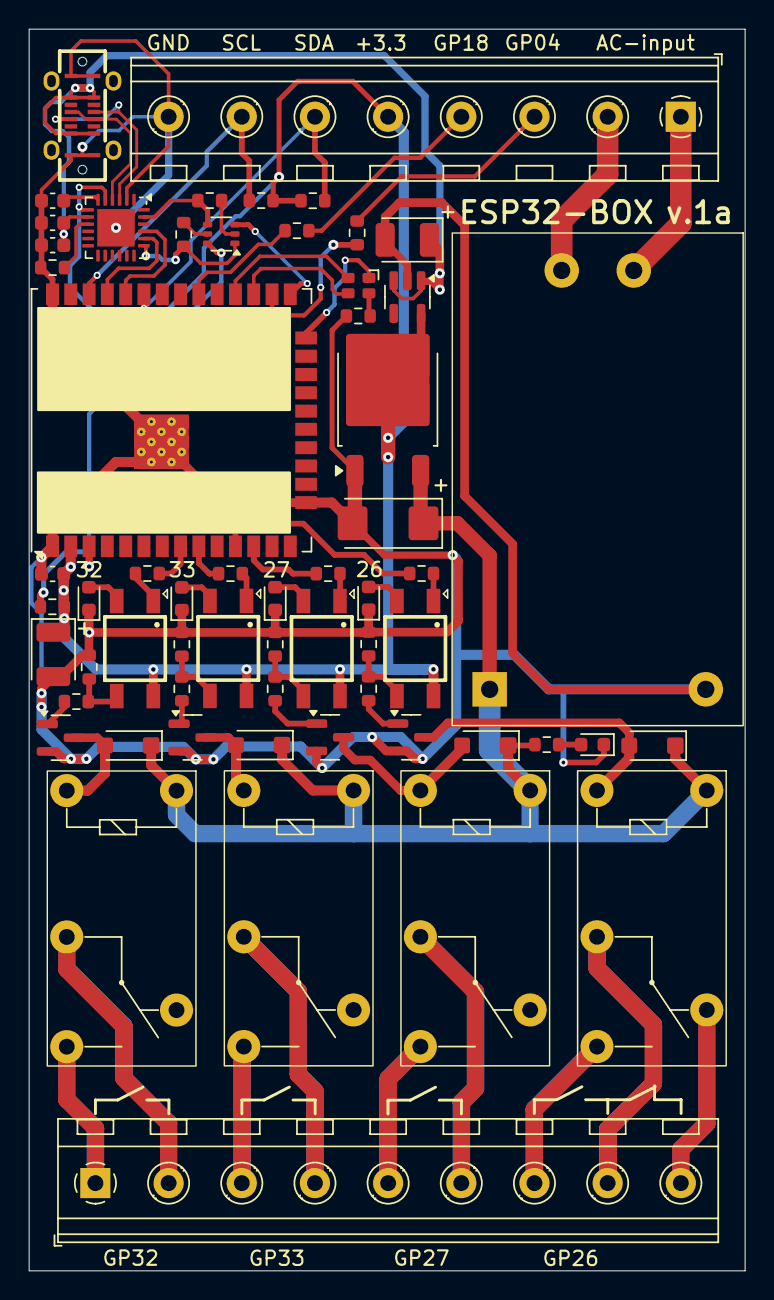
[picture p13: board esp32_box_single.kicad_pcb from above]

Board: 2 copper layers, 49.7 x 86.2 mm, 60 parts (0 on the bottom side), 62 nets.

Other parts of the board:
R9: 10k-5%; R_0603_1608Metric

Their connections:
GND: R9.1; also elsewhere on the board
unnamed 46: R9.2; also elsewhere on the board

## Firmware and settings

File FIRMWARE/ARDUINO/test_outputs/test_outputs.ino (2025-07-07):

#define LED_OK 2 // RGB-led (green)
#define LED_FAULT 16 // RGB-led (red)
#define LED_CONN 17 // RGB-led (blue)

#define RELAY_1 32 // Relay1
#define RELAY_2 33 // Relay2
#define RELAY_3 27 // Relay3
#define RELAY_4 26 // Relay4

#define INPUT_4 4
#define INPUT_18 18


// the setup function runs once when you press reset or power the board
void setup() {
  Serial.begin(115200); // for debugging
  
  pinMode(LED_OK, OUTPUT);
  pinMode(LED_FAULT, OUTPUT);
  pinMode(LED_CONN, OUTPUT);

  pinMode(RELAY_1, OUTPUT);
  pinMode(RELAY_2, OUTPUT);
  pinMode(RELAY_3, OUTPUT);
  pinMode(RELAY_4, OUTPUT);

  pinMode(INPUT_4, INPUT_PULLUP);
  pinMode(INPUT_18, INPUT_PULLUP);
  
  Serial.println("Setup ready! Start...");
}

// the loop function runs over and over again forever
void loop() {
  
  digitalWrite(RELAY_1, HIGH);
  digitalWrite(RELAY_2, LOW);
  digitalWrite(RELAY_3, LOW);
  digitalWrite(RELAY_4, LOW);
  Serial.println("Relay 1");
  delay(500);

  digitalWrite(RELAY_1, HIGH);
  digitalWrite(RELAY_2, HIGH);
  digitalWrite(RELAY_3, LOW);
  digitalWrite(RELAY_4, LOW);
  Serial.println("Relay 1+2");
  delay(500);

  digitalWrite(RELAY_1, HIGH);
  digitalWrite(RELAY_2, HIGH);
  digitalWrite(RELAY_3, HIGH);
  digitalWrite(RELAY_4, LOW);
  Serial.println("Relay 1+2+3");
  delay(500);

  digitalWrite(RELAY_1, HIGH);
  digitalWrite(RELAY_2, HIGH);
  digitalWrite(RELAY_3, HIGH);
  digitalWrite(RELAY_4, HIGH);
  Serial.println("Relay 4");
  delay(500);

  digitalWrite(RELAY_1, LOW);
  digitalWrite(RELAY_2, LOW);
  digitalWrite(RELAY_3, HIGH);
  digitalWrite(RELAY_4, HIGH);
  Serial.println("Relay 3+4");
  delay(500);
  
}

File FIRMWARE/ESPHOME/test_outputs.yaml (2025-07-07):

esphome:
  name: esp32-relay-board
  friendly_name: ESP32 Relay Board

esp32:
  board: esp32dev
  framework:
    type: arduino

logger:
api:
ota:
  platform: esphome

wifi:
  ssid: "MyWifiSsid"
  password: "MyPassword"
  ap:
    ssid: "esp32-relay-board Fallback"
    password: "fallbackpassword"

captive_portal:

# Outputs: LEDs
output:
  - platform: gpio
    pin: 2
    id: led_ok
  - platform: gpio
    pin: 16
    id: led_fault
  - platform: gpio
    pin: 17
    id: led_conn

# GPIO Switches: Relays
switch:
  - platform: gpio
    pin: 32
    id: relay_1
    name: "Relay 1"
  - platform: gpio
    pin: 33
    id: relay_2
    name: "Relay 2"
  - platform: gpio
    pin: 27
    id: relay_3
    name: "Relay 3"
  - platform: gpio
    pin: 26
    id: relay_4
    name: "Relay 4"

# Inputs: Binary Sensors with Pull-up
binary_sensor:
  - platform: gpio
    pin:
      number: 4
      mode: INPUT_PULLUP
    name: "Input 4"
    id: input_4

  - platform: gpio
    pin:
      number: 18
      mode: INPUT_PULLUP
    name: "Input 18"
    id: input_18

# Optional startup script to cycle relays like in the Arduino loop
script:
  - id: relay_cycle
    then:
      - logger.log: "Relay 1"
      - switch.turn_on: relay_1
      - switch.turn_off: relay_2
      - switch.turn_off: relay_3
      - switch.turn_off: relay_4
      - delay: 500ms

      - logger.log: "Relay 1+2"
      - switch.turn_on: relay_2
      - delay: 500ms

      - logger.log: "Relay 1+2+3"
      - switch.turn_on: relay_3
      - delay: 500ms

      - logger.log: "Relay 4"
      - switch.turn_on: relay_4
      - delay: 500ms

      - logger.log: "Relay 3+4"
      - switch.turn_off: relay_1
      - switch.turn_off: relay_2
      - delay: 500ms

# Button to manually trigger the relay cycle
button:
  - platform: template
    name: "Start Relay Cycle"
    on_press:
      then:
        - script.execute: relay_cycle

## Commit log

2025-07-07 update 2025-07-07
    [BOM_esp32_box.csv, C3151749_TYPE-C-SMD_USB4120-03-C.step, C42381015_EL357_OPTO-SMD-4_L4.4-W4.1-P2.54-LS7.0-TL.step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]
2025-07-21 CircuitPython support has been added
    CircuitPython readme and example has been added
2025-07-21 Schematics link has been added
